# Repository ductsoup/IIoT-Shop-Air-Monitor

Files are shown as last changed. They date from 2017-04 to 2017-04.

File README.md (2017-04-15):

# IIoT Shop Air Monitor
An inexpensive, IIoT connected alternative to traditional industrial stack lights and pressure switches. 

## Overview
Typically you'd use a simple pressure switch and a stacklight for a visual indication of the shop air pressure status. The cost is over $500 per unit. That offended me so I looked into more capable alternatives.

For under $100 the stack light can be replaced by a Neopixel matrix and the pressure switch with a 0-10V pressure transducer.  A WiFi capable Arduino style microcontroller adds the ability to report to a MODBUS TCP master or an MQTT broker (left as an exercise for the reader).

While configured to accept a 0-10V analog sensor, this design can also be used as a simple visual signaling device.

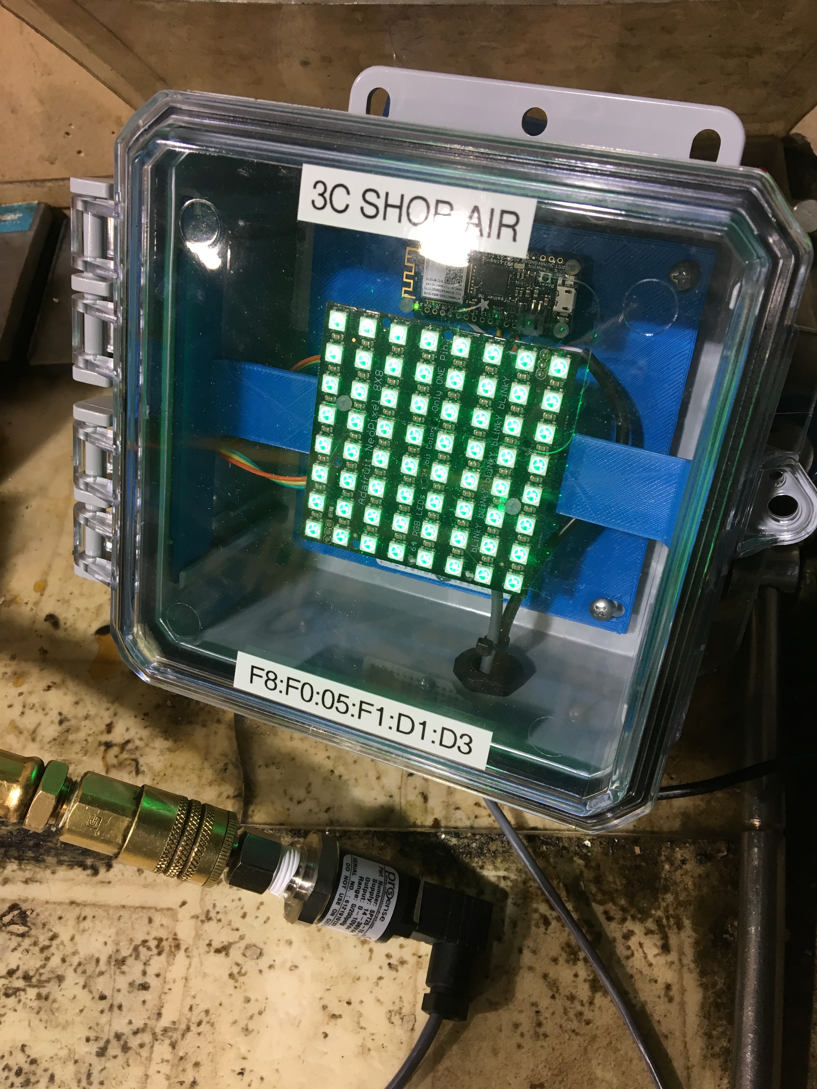
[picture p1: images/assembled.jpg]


## Bill of Materials
* [Adafruit Feather M0 WiFi - ATSAMD21 + ATWINC1500](https://www.adafruit.com/product/3010)
* [Adafruit NeoPixel NeoMatrix 8x8 - 64 RGB LED Pixel Matrix](https://www.adafruit.com/product/1487)
* [ProSense pressure transmitter, 0 to 200 psig range, 0-10 VDC analog output, 14 to 36 VDC operating voltage](https://www.automationdirect.com/adc/Shopping/Catalog/Process_Control_-a-_Measurement/Pressure_Sensors/Pressure_Transmitters/Stainless_Steel_Sensing_Element_-_DIN_Co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)
* [Pololu 5V, 5A Step-Down Voltage Regulator D24V50F5](https://www.pololu.com/product/2851)
* [74AHCT125 - Quad Level-Shifter (3V to 5V)](https://www.adafruit.com/product/1787)
* [Integra P6063C Enclosure](https://www.automationdirect.com/adc/Shopping/Catalog/Enclosures_-z-_Subpanels_-z-_Thermal_Management_-z-_Lighting/Enclosures/Padlocking_Enclosures/P6063C)
* [Standoffs](https://www.adafruit.com/product/3299)
* 3D printed sub-panel and mount
* 24V, 5A power supply

## MODBUS
### Address Map
```
S0_CurrentMillis   40001 // modpoll -m tcp -t 4:float -r 40001 [ip_addr]
S0_RSSI            40003
S0_MODE            40005
S0_THRESH_IDLE     40007 // retained
S0_THRESH_LOW      40009 // retained
S0_THRESH_HIGH     40011 // retained
S1_UPDATE_INTERVAL 40013 // retained
S1_FILTER_WEIGHT   40015 // retained
S1_PSIG_RAW        40017
S1_PSIG_OFFSET     40019 // retained
S1_PSIG            40021 
S2_R               40023
S2_G               40025
S2_B               40027
S0_STORE_CONFIG    40029
```
### Retained Storage 
Write the desired values to the retained register then write 255 to S0_STORE_CONFIG to save those settings across power cycles. As noted in the credits below, values are not retained across firmware updates.

### Smoothing
S1_PSIG_RAW is the raw output from the sensor. S1_PSIG is smoothed by S1_FILTER_WEIGHT and S1_UPDATE_INTERVAL. 

### Sensor Calibration
Set S1_PSIG_OFFSET to 0, S1_UPDATE_INTERVAL to 1000 and S1_FILTER_WEIGHT to 900 then note the value of S1_PSIG after 15 minutes. Set S1_PSIG_OFFSET to the inverse of the noted value and use S0_STORE_CONFIG to store.

### Operating Modes
Set S0_MODE to one of the following operating modes, the default is 0.

#### 0x00 Automatic (power up default)
In automatic, if the pressure is below S0_THRESH_IDLE it is assumed the compressed air system is idle and the matrix displays a low intensity blue. If the pressure is between S0_THRESH_IDLE and S0_THRESH_LOW the matrix flashes red. Between S0_THRESH_LOW and S0_THRESH_HIGH a solid green is display. If the pressure is above S0_THRESH_HIGH it displays a flashing amber.

#### 0x01 All Off
Turn the matrix off.

#### 0x02 All on at a preset color
Set S2_R, S2_G and S2_B to the desired color.

#### 0x03 Pulse at a preset color
Set S2_R, S2_G and S2_B to the desired color.

#### 0x04 Color cycle test pattern
Continuously cycle the matrix through a color wheel.

## Diffusers
The Neopixel matrix is very bright but also directional. To disperse the light add an optional diffuser. There are two styles; one that fits inside over the LED matrix and another attached to the enclosure. APLA Natural works well, t-glase is also an option.

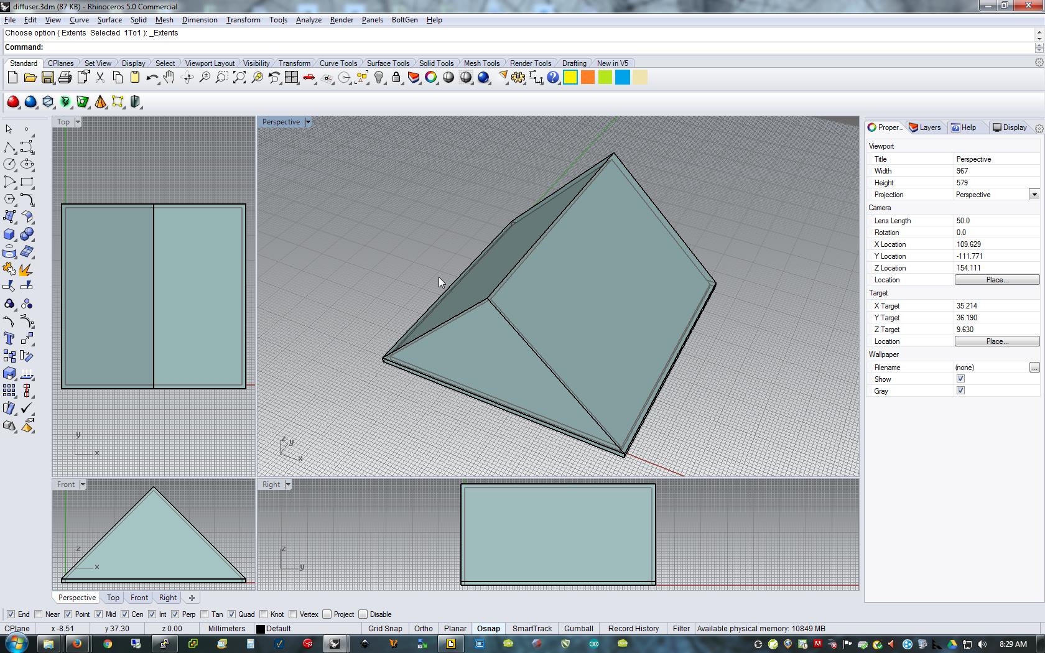
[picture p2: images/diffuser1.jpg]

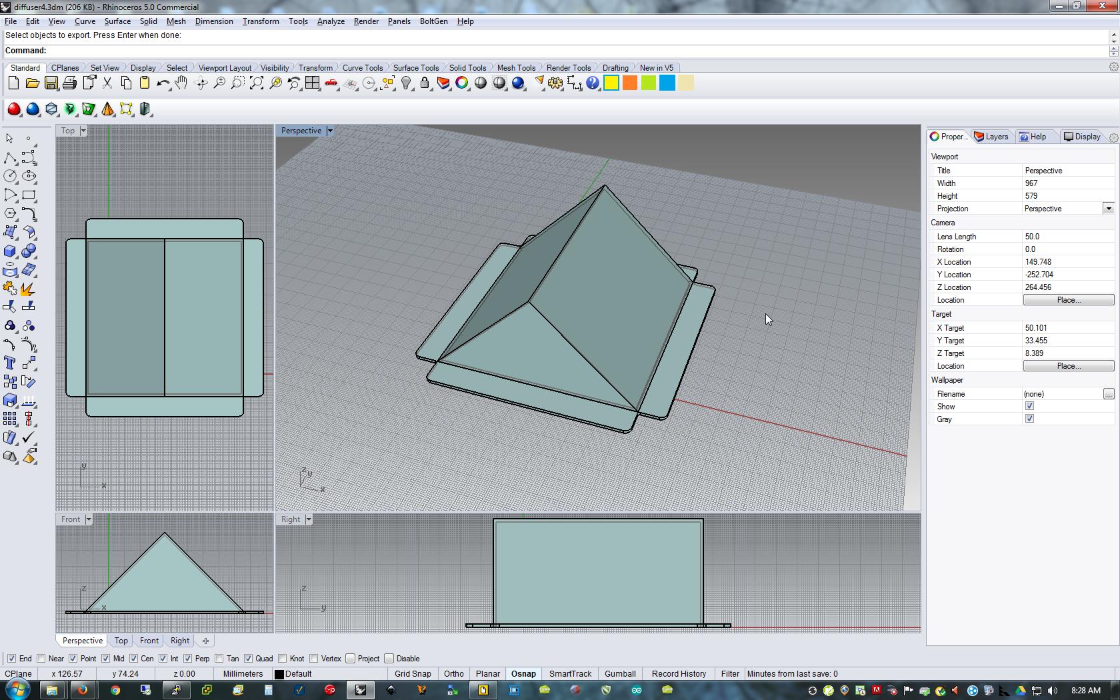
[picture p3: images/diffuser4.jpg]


## Design Notes
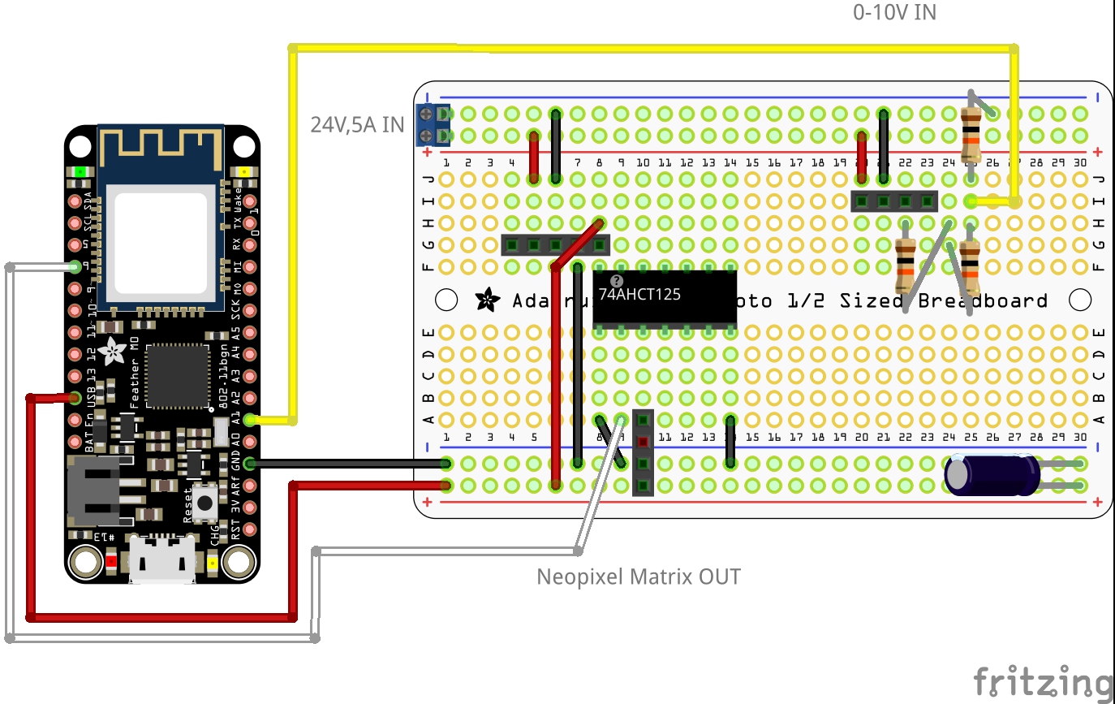
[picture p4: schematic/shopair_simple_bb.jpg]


### Power
Industrial sensors typically require 24VDC, microcontrollers 5 or 3.3VDC. The Neopixel matrix could demand up to 4A at 5VDC so we have to start with a 24VDC then use the Pololu regulator to step down to 5V.

### Level Shifting
While powered from 5V the Feather's GPIO operates at 3.3V. In order for it to reliably communicate with the 5V Neopixel matrix an 74AHCT125 or similar is necessary to shift the logic levels.

A simple 3:1 voltage divider protects the Feather's analog input by reducing 10V to 3.3V.

## Credits
Thanks to [cmaglie/FlashStorage](https://github.com/cmaglie/FlashStorage) for sharing a very clever chunk of code that emulates EEPROM on a Feather M0.

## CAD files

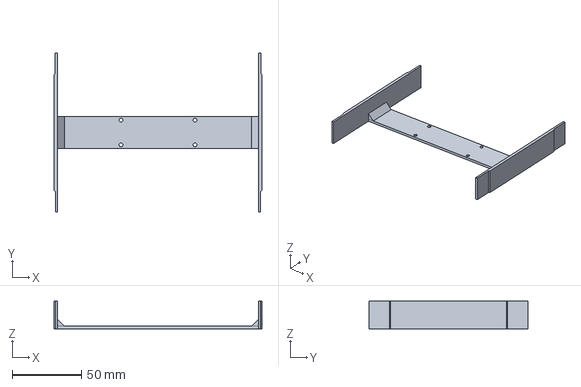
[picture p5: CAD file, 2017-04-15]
3d/mount.stp
150.0 x 114.4 x 20.0 mm

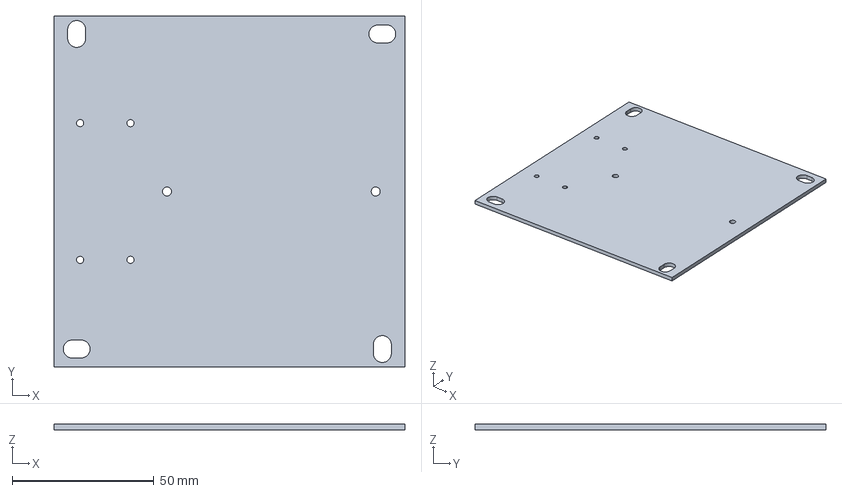
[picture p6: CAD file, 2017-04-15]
3d/subpanel.stp
124.0 x 124.0 x 2.00 mm

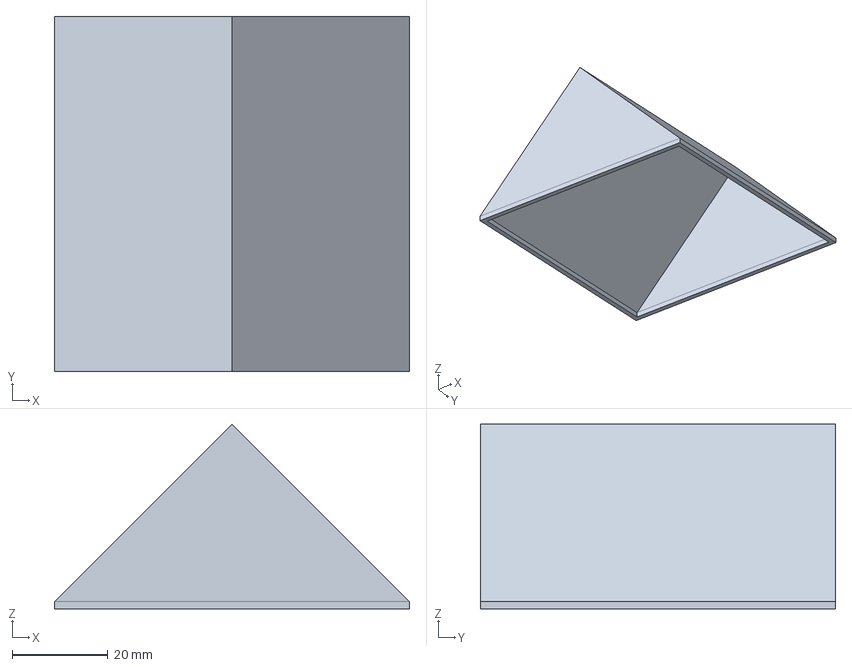
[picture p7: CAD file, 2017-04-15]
3d/diffuser1.stp
74.2 x 74.2 x 38.6 mm

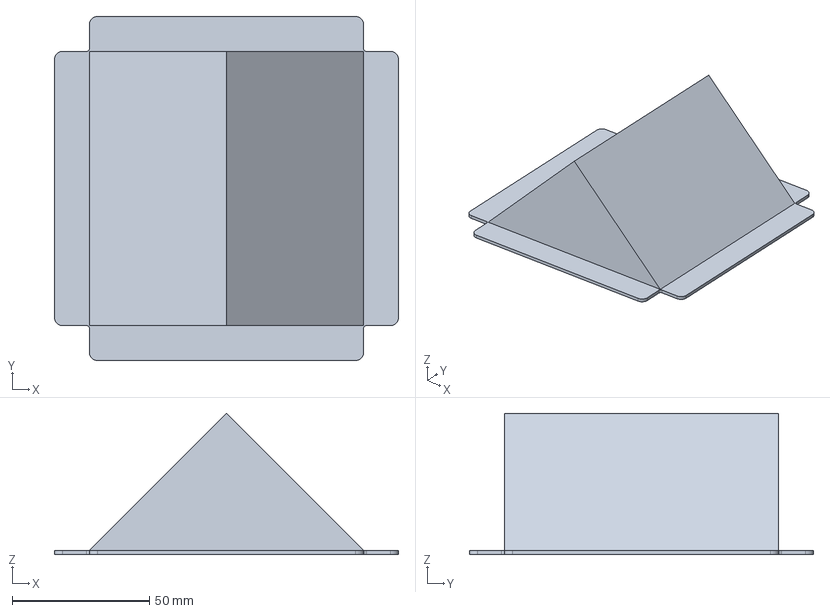
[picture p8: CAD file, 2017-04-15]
3d/diffuser4.stp
125.4 x 125.4 x 51.5 mm

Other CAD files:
3d/diffuser1.3dm
3d/diffuser1.stl
3d/diffuser4.3dm
3d/diffuser4.stl
3d/mount.stl
3d/subpanel.stl

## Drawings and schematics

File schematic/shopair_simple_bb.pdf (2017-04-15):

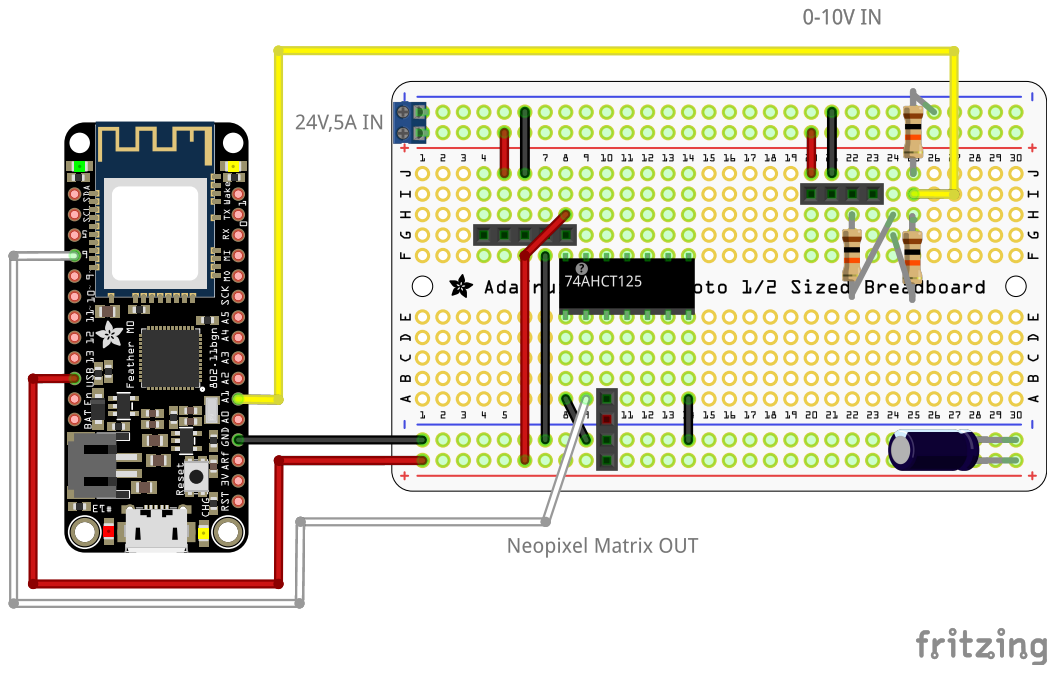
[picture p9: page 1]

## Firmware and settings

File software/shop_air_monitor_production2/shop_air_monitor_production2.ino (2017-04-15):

//
// Wiring
//
//  USB -> +5V
//  GND -> GND
//  A1  -> voltage divider
//  D6  -> Neopixel Din
//

// FlashStorage
// https://github.com/cmaglie/FlashStorage
#include "FlashAsEEPROM.h"
typedef struct {
  boolean valid;
  float thresh_idle;
  float thresh_low;
  float thresh_high;
  float update_interval;
  float filter_weight;
  float psig_offset;
} FLASH_CONFIG;
FlashStorage(flash_config, FLASH_CONFIG);
FLASH_CONFIG saved_config;

//
// Neopixel setup
//
#define PIN 6
#define LED_COUNT 64 // max 12 for testing without 24VDC PS enabled
#include "neopixel.h"

//
// MODBUS WiFi setup
//
char* access_points[][2] = {
  {"MySSID", "MyPassword"}
};
#include "ModbusTCP.h"
//
// MODBUS register map
//
#define S0_CurrentMillis   40001 // modpoll -m tcp -t 4:float -r 40001 [ip_addr]
#define S0_RSSI            40003
#define S0_MODE            40005
#define S0_THRESH_IDLE     40007 // retained
#define S0_THRESH_LOW      40009 // retained
#define S0_THRESH_HIGH     40011 // retained
#define S1_UPDATE_INTERVAL 40013 // retained
#define S1_FILTER_WEIGHT   40015 // retained
#define S1_PSIG_RAW        40017
#define S1_PSIG_OFFSET     40019 // retained
#define S1_PSIG            40021
#define S2_R               40023
#define S2_G               40025
#define S2_B               40027
#define S0_STORE_CONFIG    40029
unsigned long S1StartTime = millis();

void setup() {
  Serial.begin(9600);

  Serial.print(sizeof(FLASH_CONFIG));

  strip.begin();
  strip.setPixelColor(0, strip.Color(16, 0, 0)); // wake
  strip.show();

  delay(10000); // Give the BA cap time to charge
  strip.setPixelColor(0, strip.Color(0, 0, 16)); // not connected
  strip.show();

  saved_config = flash_config.read();
  if (!saved_config.valid) {
    Serial.println("Invalid configuration");
    saved_config.valid = true;
    saved_config.thresh_idle = 20;
    saved_config.thresh_low = 80;
    saved_config.thresh_high = 120;
    saved_config.update_interval = 500;
    saved_config.filter_weight = 4;
    saved_config.psig_offset = 0;
    setFloat(S0_STORE_CONFIG, 255);
  }
  else
    setFloat(S0_STORE_CONFIG, 0);
  setU16(S0_MODE, 255);
  setFloat(S0_THRESH_IDLE, saved_config.thresh_idle);
  setFloat(S0_THRESH_LOW, saved_config.thresh_low);
  setFloat(S0_THRESH_HIGH, saved_config.thresh_high);
  setFloat(S1_UPDATE_INTERVAL, saved_config.update_interval);
  setFloat(S1_FILTER_WEIGHT, saved_config.filter_weight);
  setFloat(S1_PSIG_OFFSET, saved_config.psig_offset);

  analogReadResolution(12);           // bump the ADC resolution from 10 to 12 bits because we can

  modbus_begin();

  strip.setPixelColor(0, strip.Color(0, 16, 0)); // connected
  strip.show();
}

void loop() {
  uint32_t curMillis = millis();
  static int16_t i, j, k;
  byte r, g, b;
  static byte mode, last_mode;
  float psig, ti, tl, th;

  //
  // Save configuration if this register contains 255, confirm the
  // configuration has been saved by resetting the register to 0
  //
  if (getFloat(S0_STORE_CONFIG) == 255.0) {
    for (i = 0; i < strip.numPixels(); i++)
      strip.setPixelColor(i, strip.Color(0, 16, 16));
    strip.show();
    saved_config.valid = true;
    saved_config.thresh_idle = getFloat(S0_THRESH_IDLE);
    saved_config.thresh_low = getFloat(S0_THRESH_LOW);
    saved_config.thresh_high = getFloat(S0_THRESH_HIGH);
    saved_config.update_interval = getFloat(S1_UPDATE_INTERVAL);
    saved_config.filter_weight = getFloat(S1_FILTER_WEIGHT);
    saved_config.psig_offset = getFloat(S1_PSIG_OFFSET);
    flash_config.write(saved_config);
    setFloat(S0_STORE_CONFIG, 0);
    Serial.println("Wrote configuration to FLASH memory");
  }

  //
  // Update MODBUS registers
  //
  setFloat(S0_CurrentMillis, millis());
  setFloat(S0_RSSI, WiFi.RSSI());

  //
  // The sensor reports 0-10V from 0-200 psig and there is a 3:1 voltage divider to
  // scale 0-10 to 0-3.3. The analog input reports 0-3.3V from 0 to 4096. The divider
  // and the reference cancel out. To read in psig multiply by the sensor's full
  // scale then divide by the ADC steps.
  //
  if (curMillis - S1StartTime > getFloat(S1_UPDATE_INTERVAL)) {
    psig = 200.0 * analogRead(A1) / 4096.0;
    setFloat(S1_PSIG_RAW, psig);
    setFloat(S1_PSIG, max((psig + getFloat(S1_PSIG_OFFSET) + getFloat(S1_PSIG) * (getFloat(S1_FILTER_WEIGHT) - 1.0)) / getFloat(S1_FILTER_WEIGHT), 0));
    S1StartTime = curMillis;
  }

  //
  // Process annunciator actions
  //
  mode = byte(getFloat(S0_MODE));
  switch (mode) {
    //
    //    0 to  20 Low Blue
    //   20 to  80 Flash Red
    //   80 to 120 Low Green
    //    over 120 Flash Red
    //
    case 0: // automatic
      if (mode != last_mode) j = 0;
      ti = getFloat(S0_THRESH_IDLE);
      tl = getFloat(S0_THRESH_LOW);
      th = getFloat(S0_THRESH_HIGH);
      psig = getFloat(S1_PSIG);
      // idle
      if (getFloat(S1_PSIG) < ti) {
        for (i = 0; i < strip.numPixels(); i++) {
          strip.setPixelColor(i, strip.Color(0, 0, 4));
          modbus_run();
        }
      }
      // pressure is too low
      else if (getFloat(S1_PSIG) >= ti && getFloat(S1_PSIG) < tl) {
        --j = j > 0 ? j : 255;
        for (i = 0; i < strip.numPixels(); i++) {
          strip.setPixelColor(i, strip.Color(j, 0, 0));
          modbus_run();
        }
      }
      // pressure is ok
      else if (getFloat(S1_PSIG) >= tl && getFloat(S1_PSIG) < th)  {
        --j = j > 0 ? j : 255;
        for (i = 0; i < strip.numPixels(); i++) {
          strip.setPixelColor(i, strip.Color(0, 16, 0));
          modbus_run();
        }
      }
      // pressure is too high
      else {
        --j = j > 0 ? j : 255;
        for (i = 0; i < strip.numPixels(); i++) {
          strip.setPixelColor(i, strip.Color(j, j, 0));
          modbus_run();
        }
      }
      strip.show();
      break;

    case 1: // all off
      for (i = 0; i < strip.numPixels(); i++) {
        strip.setPixelColor(i, strip.Color(0, 0, 0));
        modbus_run();
      }
      strip.show();
      break;

    case 2: // all on at a preset color
      r = constrain(getFloat(S2_R), 0, 255);
      g = constrain(getFloat(S2_G), 0, 255);
      b = constrain(getFloat(S2_B), 0, 255);
      for (i = 0; i < strip.numPixels(); i++) {
        strip.setPixelColor(i, strip.Color(r, g, b));
        modbus_run();
      }
      strip.show();
      break;

    case 3: // pulse
      if (mode != last_mode) j = 255;
      r = constrain(getFloat(S2_R), 0, 1);
      g = constrain(getFloat(S2_G), 0, 1);
      b = constrain(getFloat(S2_B), 0, 1);
      if (!(r || g || b)) {
        r = 1;
        g = b = 0;
      }
      --j = j > 0 ? j : 255;
      for (i = 0; i < strip.numPixels(); i++) {
        strip.setPixelColor(i, strip.Color(j * r, j * g, j * b));
        modbus_run();
      }
      strip.show();
      break;

    case 4: // rainbow attention getter
      if (mode != last_mode) j = 0;
      ++j = j > 255 ? 0 : j;
      for (i = 0; i < strip.numPixels(); i++) {
        strip.setPixelColor(i, Wheel(j));
        modbus_run();
      }
      strip.show();
      //Serial.println(j);
      break;

    default:
      setFloat(S0_MODE, 0);
      modbus_run();
      break;
  }
  last_mode = mode;
}

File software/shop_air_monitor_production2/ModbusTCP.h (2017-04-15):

/*******************************************************************************
   ModbusTCP.h

   Lightweight Modbus TCP 32-bit slave for Arduino.

   Three MODBUS function codes are supported; reading (0x04) and writing (0x10)
   of holding registers and function 0x06 for compatiblilty.

   Three Modbus encodings are supported; UInt16, UInt32 and Float (Float and
   Double are identical on Arduino Uno). With these three primitive types you
   can also support Int16, Int32, or packed bits (coils).

   Holding register addressing begins at 40001 and are contiguous.

   Data is stored in native MODBUS UInt16 registers. To make it less error
   prone, get and set functions are included for each encoding that also do
   error checking. If you're crushed for resources feel free to comment out
   the define statements and write to the registers directly.

   Testing
   This code was developed and tested using modpoll and Inductive Automation
   Ignition quick client running in trial mode.

   http://www.modbusdriver.com/modpoll.html
   https://www.inductiveautomation.com/scada-software

   Credits

   https://code.google.com/p/mudbus/

   Thanks to Dee Wykoff and Martin Pettersson for making the Mudbus library
   available as a place to start.

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
   THE SOFTWARE IS PROVIDED "AS IS", WITHOUT WARRANTY OF ANY KIND, EXPRESS OR
   IMPLIED, INCLUDING BUT NOT LIMITED TO THE WARRANTIES OF MERCHANTABILITY,
   FITNESS FOR A PARTICULAR PURPOSE AND NONINFRINGEMENT. IN NO EVENT SHALL THE
   AUTHORS OR COPYRIGHT HOLDERS BE LIABLE FOR ANY CLAIM, DAMAGES OR OTHER
   LIABILITY, WHETHER IN AN ACTION OF CONTRACT, TORT OR OTHERWISE, ARISING FROM,
   OUT OF OR IN CONNECTION WITH THE SOFTWARE OR THE USE OR OTHER DEALINGS IN
   THE SOFTWARE.
*/

//
// Application specific, adjust as necessary
//
#define MB_PORT 502
#define MB_REGISTERS_MAX 32
uint16_t mb_reg[MB_REGISTERS_MAX];

//
// Comment out features you don't need to save space
//
#define MB_DEBUG
#define MB_Float
#define MB_UInt32
#define MB_UInt16

//
// Adafruit Feather M0 WiFi - ATSAMD21 + ATWINC1500
// https://www.adafruit.com/product/3010
//
#include <SPI.h>
#include <WiFi101.h>
#define WINC_CS   8
#define WINC_IRQ  7
#define WINC_RST  4
#define WINC_EN   2


/*******************************************************************************
  It's probably best not to edit below here unless you're sure you know what
  you're doing
 *******************************************************************************/

//
// WiFi server
//
int status = WL_IDLE_STATUS;
WiFiServer server(MB_PORT);
boolean alreadyConnected = false; // whether or not the client was connected previously

/*******************************************************************************

   MODBUS Reference

   http://www.csimn.com/CSI_pages/Modbus101.html

   Modicon convention notation

   0x = Coil = 00001-09999
   1x = Discrete Input = 10001-19999
   3x = Input Register = 30001-39999
   4x = Holding Register = 40001-49999

   Modbus protocol defines a holding register as 16 bits wide; however, there is
   a widely used defacto standard for reading and writing data wider than 16
   bits. The most common are IEEE 754 floating point, and 32-bit integer. The
   convention may also be extended to double precision floating point and 64-bit
   integer data.

   http://www.freemodbus.org/

   ----------------------- MBAP Header --------------------------------------

   <------------------------ MODBUS TCP/IP ADU(1) ------------------------->
   <----------- MODBUS PDU (1') ---------------->
   +-----------+---------------+------------------------------------------+
   | TID | PID | Length | UID  |Code | Data                               |
   +-----------+---------------+------------------------------------------+
   |     |     |        |      |
   (2)   (3)   (4)      (5)    (6)
   (2)  ... MB_TCP_TID          = 0 (Transaction Identifier - 2 Byte)
   (3)  ... MB_TCP_PID          = 2 (Protocol Identifier - 2 Byte)
   (4)  ... MB_TCP_LEN          = 4 (Number of bytes - 2 Byte)
   (5)  ... MB_TCP_UID          = 6 (Unit Identifier - 1 Byte)
   (6)  ... MB_TCP_FUNC         = 7 (Modbus Function Code)

   (1)  ... Modbus TCP/IP Application Data Unit
   (1') ... Modbus Protocol Data Unit

 *******************************************************************************/

//
// MODBUS request buffer
//
uint8_t mb_adu[260];
int16_t iTXLen = 0;       // response packet length

//
// MODBUS Function Codes
//
#define MB_FC_NONE 0
#define MB_FC_READ_COILS 1
#define MB_FC_READ_DISCRETE_INPUT 2
#define MB_FC_READ_REGISTERS 3 // implemented
#define MB_FC_READ_INPUT_REGISTERS 4
#define MB_FC_WRITE_COIL 5
#define MB_FC_WRITE_REGISTER 6 // implemented
#define MB_FC_WRITE_MULTIPLE_COILS 15
#define MB_FC_WRITE_MULTIPLE_REGISTERS 16 // implemented
//
// MODBUS Error Codes
//
#define MB_EC_NONE 0
#define MB_EC_ILLEGAL_FUNCTION 1
#define MB_EC_ILLEGAL_DATA_ADDRESS 2
#define MB_EC_ILLEGAL_DATA_VALUE 3
#define MB_EC_SLAVE_DEVICE_FAILURE 4
//
// MODBUS MBAP offsets
//
#define MB_TCP_TID          0 // ignored
#define MB_TCP_PID          2 // ignored
#define MB_TCP_LEN          4
#define MB_TCP_UID          6 // ignored
#define MB_TCP_FUNC         7
#define MB_TCP_DATA         8

#ifdef MB_Float
int setFloat(uint16_t iAddress, float fValue) {

  int iRet;
  union {
    float f;
    uint16_t w[2];
  }
  fw;

  for (iRet = 0 ; !iRet ; iRet = 2) {
    if ((iAddress -= 40001) < 0 || (iAddress + 1) >= MB_REGISTERS_MAX) // invalid address
      break;
    fw.f = fValue;
    mb_reg[iAddress++] = fw.w[0];
    mb_reg[iAddress] = fw.w[1];
  }
  return (iRet);
}
float getFloat(uint16_t iAddress) {

  union {
    float fRet;
    uint16_t w[2];
  }
  fw;

  if ((iAddress -= 40001) < 0 || (iAddress + 1) >= MB_REGISTERS_MAX) // invalid address
    fw.fRet = NULL;
  else {
    fw.w[0] = mb_reg[iAddress++];
    fw.w[1] = mb_reg[iAddress];
  }
  return (fw.fRet);
}
#endif
#ifdef MB_UInt32
int setU32(uint16_t iAddress, uint32_t iValue) {

  int iRet;
  for (iRet = 0 ; !iRet ; iRet = 2) {
    if ((iAddress -= 40001) < 0 || (iAddress + 1) >= MB_REGISTERS_MAX) // invalid address
      break;
    mb_reg[iAddress++] = iValue & 0xffff;
    mb_reg[iAddress] = iValue >> 16;
  }
  return (iRet);
}
uint32_t getU32(uint16_t iAddress) {

  uint32_t lRet;

  if ((iAddress -= 40001) < 0 || (iAddress + 1) >= MB_REGISTERS_MAX) // invalid address
    lRet = NULL;
  else {
    lRet = (long(mb_reg[iAddress++]) | (long(mb_reg[iAddress + 1]) << 16));
  }
  return (lRet);
}
#endif
#ifdef MB_UInt16
int setU16(uint16_t iAddress, uint16_t iValue) {

  int iRet;
  for (iRet = 0 ; !iRet ; iRet = 1) {
    if ((iAddress -= 40001) < 0 || (iAddress >= MB_REGISTERS_MAX)) // invalid address
      break;
    mb_reg[iAddress] = iValue;
  }
  return (iRet);
}
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

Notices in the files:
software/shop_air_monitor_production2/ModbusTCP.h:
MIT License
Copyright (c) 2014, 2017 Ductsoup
